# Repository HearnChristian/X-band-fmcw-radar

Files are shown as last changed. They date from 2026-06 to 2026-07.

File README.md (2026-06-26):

# (actually K)-Band FMCW Radar

A frequency-modulated continuous-wave (FMCW) radar front-end designed in KiCad —
a single-board transceiver intended for **ground-based ranging and weather /
precipitation sensing**. This repository holds the schematic capture, the
project's custom KiCad libraries, and the generated netlist. Work in progress.

## Architecture

FMCW radar works by transmitting a continuous tone whose frequency is swept
(chirped) linearly in time, then mixing the received echo against the
transmitted signal. The frequency of the resulting beat tone is proportional to
target range, so the whole signal chain is built around generating a clean,
linear chirp and digitizing the low-frequency beat note.

```
  Reference        Chirp synth        RF transceiver        Driver amp
  ┌────────┐      ┌──────────┐       ┌──────────────┐      ┌──────────┐
  │  TCXO  │─────▶│ ADF4159  │──────▶│ BGT24LTR11N16│─────▶│AMM-8211PSM│──▶ TX
  │ ref clk│      │ PLL/ramp │       │ 24 GHz Tx/Rx │      │ driver PA │
  └────────┘      └──────────┘       └──────┬───────┘      └──────────┘
                                            │ IF (beat)
                                            ▼
                       ┌──────────┐   ┌──────────┐   ┌──────────┐
                  Rx ──│ OPA1656  │──▶│ ADS8353  │──▶│ FT2232H  │──▶ USB host
                       │ IF amp   │   │ 16b ADC  │   │ USB 2.0  │
                       └──────────┘   └──────────┘   └──────────┘
```

## Key components

| Block | Part | Function |
|---|---|---|
| Chirp synthesizer | **ADF4159** | Fractional-N PLL with onboard ramp generator — produces the linear FMCW sweep |
| RF transceiver | **BGT24LTR11N16** | 24 GHz SiGe transmit/receive front-end with integrated VCO and downconversion |
| Driver amplifier | **AMM-8211PSM** | 22–57 GHz GaAs MMIC driver amp boosting the transmit chain |
| IF / baseband | **OPA1656** | Low-noise, low-distortion op-amp conditioning the beat-note signal |
| Data converter | **ADS8353** | Dual 16-bit SAR ADC sampling the IF |
| Host interface | **FT2232HL** | USB 2.0 bridge for control + data streaming |
| Reference clock | **ECS-TXO-2520MV** | TCXO frequency reference |
| Power | **TPS7A4700 / TPS7A2018 / TPS7A2033** | Ultra-low-noise LDOs for clean RF/analog rails |
| Config | **93LC56B** | EEPROM for FT2232 descriptor |

## Custom library work

The **AMM-8211PSM** driver amplifier had no vendor-supplied EDA data — only a
datasheet — so its schematic symbol and PCB footprint were built from scratch
from the Marki Microwave mechanical drawings:

```
AMM-8211PSM.kicad_sym                                          custom symbol
AMM-8211PSM.pretty/QFN-16-1EP_3x3mm_P0.5mm_EP1.1x1.1mm_Marki.kicad_mod   custom footprint
```

The footprint is a 3 × 3 mm 16-lead QFN, 0.5 mm pitch, with a 1.10 × 1.10 mm
exposed ground paddle and a 3 × 3 array of thermal vias, matching the Marki
outline drawing and pin assignment.

## Repository layout

```
Radar1.kicad_pro      KiCad project
Radar1.kicad_sch      Schematic (in progress)
Radar1.kicad_pcb      PCB layout (not yet started)
Radar1.net            Exported netlist
AMM-8211PSM.kicad_sym Custom symbol (see above)
AMM-8211PSM.pretty/   Custom footprint library
sym-lib-table         Project symbol-library table
fp-lib-table          Project footprint-library table
```

## Tools

Designed in [KiCad](https://www.kicad.org/) 9. Open `Radar1.kicad_pro` to view
the schematic.

---

*Author: Christian Hearn*

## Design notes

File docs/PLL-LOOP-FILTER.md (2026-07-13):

# PLL Loop Filter Design (Rev-E)

Chirp synthesizer loop: ADF4159 (PFD + charge pump) locks the BGT24LTR11
VCO through its ÷16 divider output. This note replaces the schematic-capture
placeholder values with a computed design (`tools/pll_loop_filter.py`).

## Loop parameters

| Parameter | Value | Source |
|---|---|---|
| f_REF = f_PFD | 50 MHz | ECS-TXO-2520MV-500 (Y1), R-counter = 1 |
| f_VCO | 24.05–24.25 GHz | BGT24LTR11 DS Table 5 (R_TUNE = 16 kΩ) |
| N (VCO→PFD) | 483 | includes BGT24 ÷16 (ADF4159 INT ≈ 30.2, frac) |
| Kvco | 720 MHz/V typ, 2000 MHz/V max | BGT24LTR11 DS Table 5 |
| V_TUNE range | 0.7–2.5 V | BGT24LTR11 DS; ADF4159 CP compliance 0.5–2.8 V ✓ |
| Icp | 2.5 mA design point | RSET = 5.1 kΩ → 0.31–5 mA in 16 steps |

## Topology fix

The captured filter was an all-shunt RC ladder (C17 ∥ → R3 → C18 ∥ → R4 →
C19 ∥ → V_TUNE). A current-driven RC ladder has **no finite zero at the
output node**, so a type-2 loop built on it is unconditionally unstable —
confirmed by exact network analysis. **Rev-E moves R4's input from the
R3/C18 junction to the charge-pump node**, restoring the standard 3rd-order
passive filter: the R3+C18 series branch at CPOUT provides the stabilizing
zero, R4/C19 form the spur-filter pole.

```
CPOUT ──┬────┬───── R4 (560R) ───┬──── V_TUNE
        │    │                   │
      C17   R3 (270R)          C19 (270pF)
     910pF   │                   │
        │  C18 (15nF)           GND
       GND   │
            GND
```

## Values and verified performance (exact ladder analysis)

C17 = 910 pF, R3 = 270 Ω, C18 = 15 nF, R4 = 560 Ω, C19 = 270 pF (E12/E24).

| Corner | f_c | Phase margin |
|---|---|---|
| Kvco typ, Icp 2.5 mA (design) | 146 kHz | 52° |
| Kvco max, Icp 2.5 mA | 331 kHz | 36° |
| Kvco typ, Icp 1.25 mA | 81 kHz | 51° |
| Kvco max, Icp 1.25 mA | 193 kHz | 49° |
| Kvco typ, Icp 5 mA | 259 kHz | 43° |

150 kHz sits near the noise-optimal crossover (ADF4159 in-band floor
≈ −90 dBc/Hz at N = 483 meets the VCO's −80 dBc/Hz @100 kHz, −20 dB/dec
a little above 300 kHz) and comfortably tracks the FMCW ramp
(250 MHz / 1 ms ≈ 0.35 V/ms on V_TUNE).

## Firmware notes

- Program Icp = 2.5 mA (setting 8/16). If lab tuning shows Kvco at the
  high end, drop to 1.25 mA rather than raising the bandwidth.
- R-counter = 1, reference doubler/divider off (f_PFD = 50 MHz).
- Keep **VCC_PTAT = 0 V**: the BGT24 divider is ÷16 only when V_PTAT is
  disabled; at 3.3 V it becomes ÷8192 and the loop constants are wrong.
- MUXOUT is open-drain 1.8 V logic (R22 pull-up to +1V8, Rev-D).

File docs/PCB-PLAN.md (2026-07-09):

# PCB Plan — Stackup Trade & Floorplan (pre-layout)

Base: schematic `21be641` (electrically identical to Rev-C `4aef776`, netlist-verified).
Date: 2026-07-09.

## Substrate decision

Only the three 24 GHz runs (TX chain to J3, RX feed from J4) and the 1.5 GHz
divided LO care about the substrate; everything else is DC/SPI/IF.

| Option | Dk | tan δ | ~Loss @24 GHz | Z₀ tol | Verdict |
|---|---|---|---|---|---|
| All FR4 | 4.2–4.6 (uncontrolled) | ~0.020 | 0.5–0.8 dB/cm | ±8–10 % | Reject — loss + Dk uncertainty eat the PA gain budget |
| **Hybrid RO4350B (10 mil) over FR4** | 3.48 ± 0.05 | 0.0037 | 0.10–0.15 dB/cm | ±2–3 % | **Pick** — all RF is on L1/L2; FR4 below carries power/digital |
| Full RO4350B | 3.48 ± 0.05 | 0.0037 | 0.10–0.15 dB/cm | ±2–3 % | Overkill — inner layers are DC/digital |

**Stackup (≈1.5 mm, ENIG):** L1 RF/signal — RO4350B 0.254 mm — L2 solid GND —
FR4 core ≈0.9 mm — L3 power — prepreg — L4 signal/GND.
50 Ω GCPW starting point: w ≈ 0.50 mm, gap ≈ 0.25 mm (field-solve against fab stackup).

## Floorplan (board ≈ 60 × 42 mm)

- **West edge:** J3 (TX) / J4 (RX) end-launch, ≥26.5 GHz rated (2.92 mm preferred).
  U12 PA driver between U1 and J3; U1 BGT24 center-west. 24 GHz GCPW with via
  fences (pitch ≤ 0.8 mm) both sides; stitching ring around RF zone.
- **PLL:** U2 ADF4159 east of U1; loop filter tight, guarded, nothing switching
  within 5 mm; Y1 50 MHz TCXO short/direct into REFIN.
- **Center:** IF chain U1 → U3 (OPA1656 ×3) → U8 ADS8353; U15 REF5025 adjacent.
- **East edge:** U7 FT2232H, U11 12 MHz, U10 EEPROM, J1 USB-C.
- **South strip:** J2 barrel (SE) → U6 5 V LDO (+ thermal pour) → LDO row.
  U9 ADP5600 (−VGG charge pump, the only switcher) far corner from RX, LC
  post-filter to PA gate. +3V3_RF / +3V3_DIG copper split mirrors the Rev-C rail split.
- Thermal: EP via arrays under U1, U12, U6, U13.

## Blockers before placement

1. **CRITICAL — ADF4159 SPI overvoltage.** FT2232H drives CLK/DATA/LE/CE/TXDATA
   at 3.3 V; ADF4159 digital abs-max = DVDD + 0.3 V = 2.1 V (datasheet Table 4).
   MUXOUT readback (1.8 V logic → 3.3 V-bank input) is marginal in reverse.
   Fix (no new parts): power FT2232H ADBUS-bank VCCIO from +1V8 (VCCIO spec
   1.62–3.63 V), and move ADS8353 DVDD from +3V3_RF to +1V8 (also removes ADC
   digital noise from the RF rail).
2. Footprint pass: ~12 symbols unassigned; 5 libs missing from `fp-lib-table`.
3. Sync embedded symbols with libs (USB4215-03-A, AMM-8211PSM mismatch).
4. Spec barrel input 6 V nominal (≤6.5 V) or add buck before U6 — LDO drops
   (VIN−5 V) × ~0.45 A.
5. Optional: route U1 V_PTAT to a spare ADC channel for temperature telemetry.

## Verified correct in this review

PA sequencing (ADP5600 PGOOD gates +3V0_PA enable), PA bias (Vd = 3 V/175 mA =
datasheet nominal), TPS7A4700 straps (5.0 V / 3.0 V exact), FT2232 VCORE loop,
ADF4159 rail split (AVDD 3.3 / DVDD 1.8). ERC "errors" are symbol pin-type
pedantry; netlist has no floating nets.

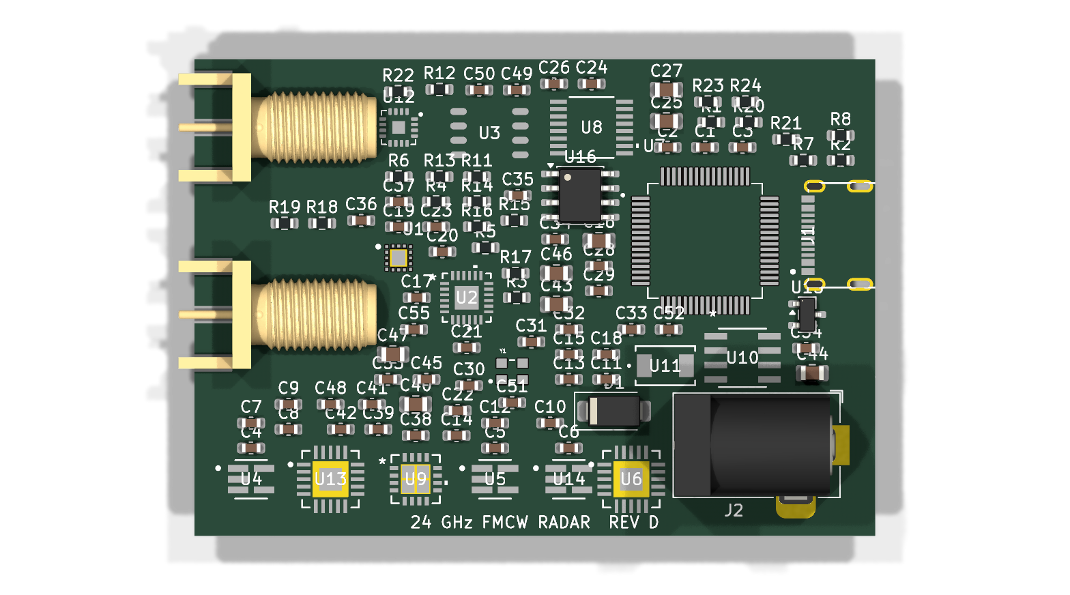
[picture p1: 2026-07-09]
docs/board-placement-top.png

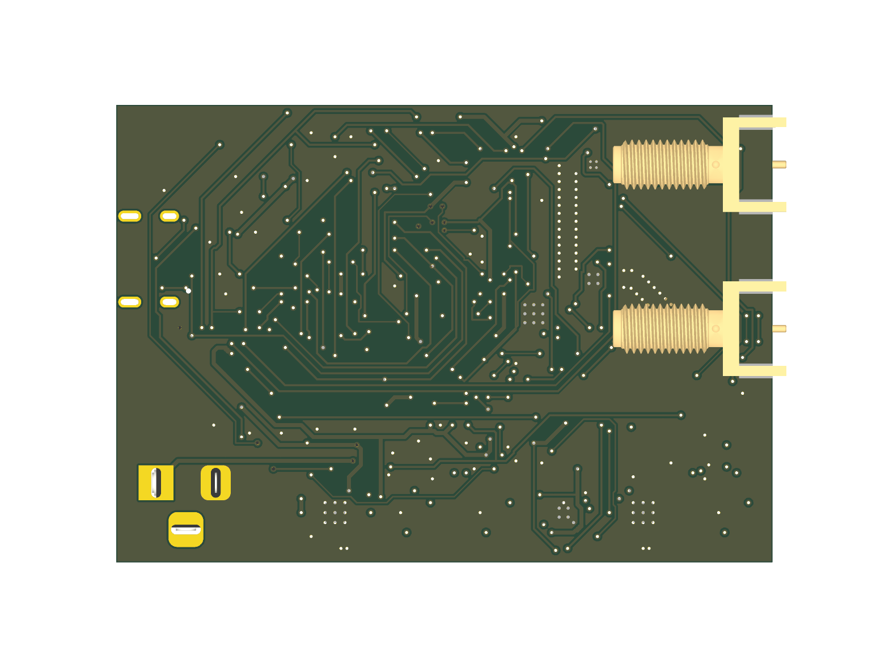
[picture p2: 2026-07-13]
docs/board-bottom.png

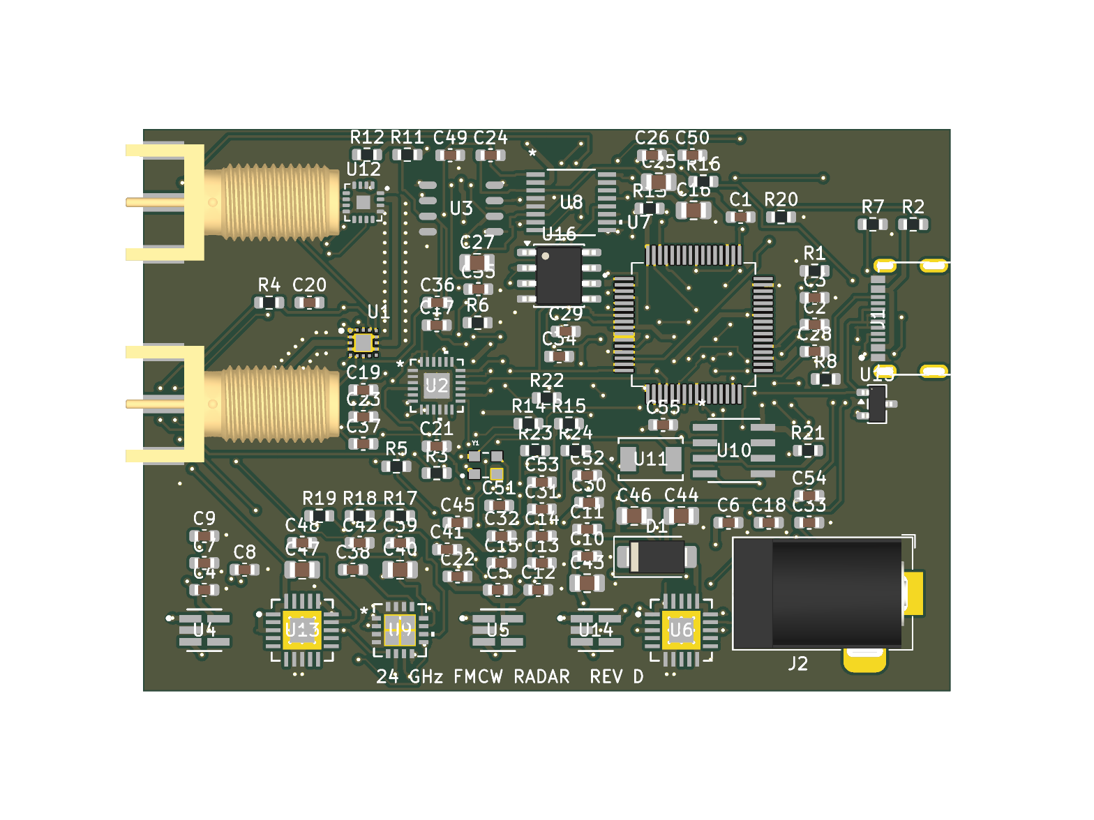
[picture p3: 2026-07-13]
docs/board-top.png

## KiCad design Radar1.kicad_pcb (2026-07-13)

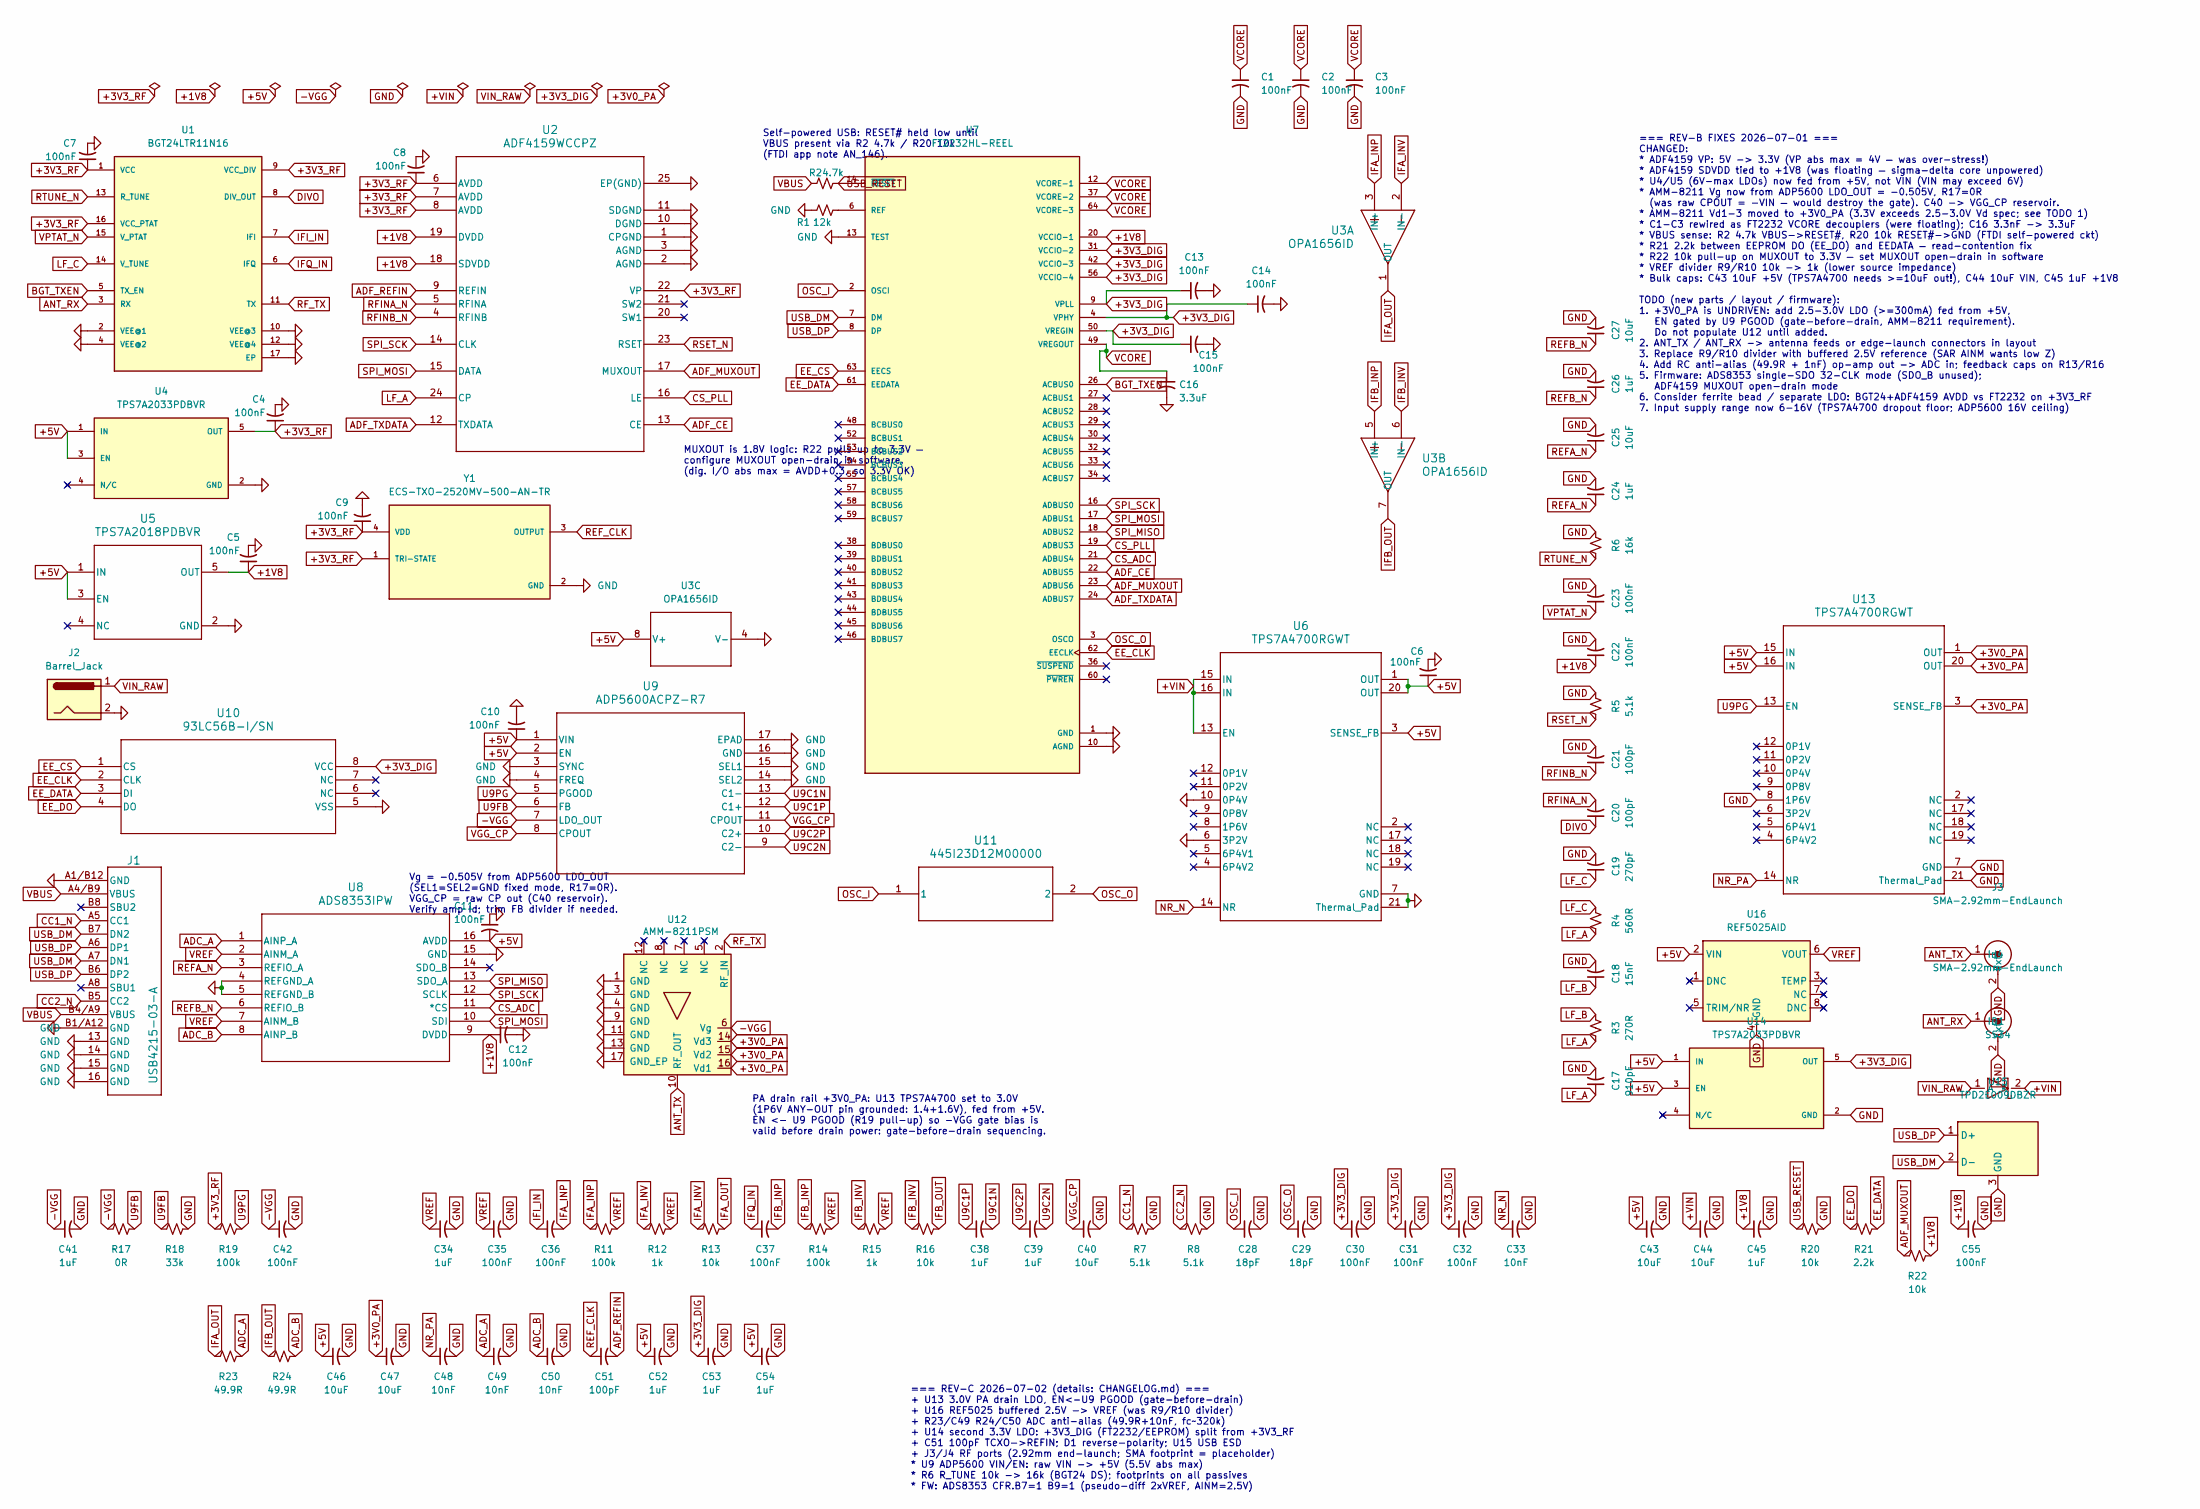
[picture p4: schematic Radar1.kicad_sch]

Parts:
C1, C2, C3, C4, C5, C6, C7, C8, C9, C10, C11, C12, C13, C14, C15, C22, C23, C30, C31, C32, C35, C36, C37, C42, C55: 100nF; C_0603_1608Metric
C16: 3.3uF; C_0805_2012Metric
C17: 910pF; C_0603_1608Metric
C18: 15nF; C_0603_1608Metric
C19: 270pF; C_0603_1608Metric
C20, C21, C51: 100pF; C_0603_1608Metric
C24, C26, C34, C38, C39, C41, C45, C52, C53, C54: 1uF; C_0603_1608Metric
C25, C27, C40, C43, C44, C46, C47: 10uF; C_0805_2012Metric
C28, C29: 18pF; C_0603_1608Metric
C33, C48, C49, C50: 10nF; C_0603_1608Metric
D1: SS34; D_SMA
J1: USB4215-03-A; CONN_8p94X6p5X3p16_12L_GCC
J2: Barrel_Jack; BarrelJack_Horizontal
J3, J4: SMA-2.92mm-EndLaunch; SMA_Amphenol_132289_EdgeMount
R1: 12k; R_0603_1608Metric
R2: 4.7k; R_0603_1608Metric
R3: 270R; R_0603_1608Metric
R4: 560R; R_0603_1608Metric
R5, R7, R8: 5.1k; R_0603_1608Metric
R6: 16k; R_0603_1608Metric
R11, R14, R19: 100k; R_0603_1608Metric
R12, R15: 1k; R_0603_1608Metric
R13, R16, R20, R22: 10k; R_0603_1608Metric
R17: 0R; R_0603_1608Metric
R18: 33k; R_0603_1608Metric
R21: 2.2k; R_0603_1608Metric
R23, R24: 49.9R; R_0603_1608Metric
U1: BGT24LTR11N16; PQFN50P240X240X77-17N-V
U2: ADF4159WCCPZ; CP_24_10
U3: OPA1656ID; D0008A_N
U4, U14: TPS7A2033PDBVR; DBV0005A-IPC_A; PARTREV H
U5: TPS7A2018PDBVR; DBV0005A-IPC_A
U6, U13: TPS7A4700RGWT; RGW0020A-IPC_A
U7: FT2232HL-REEL; QFP50P1200X1200X160-64N
U8: ADS8353IPW; PW16_TEX
U9: ADP5600ACPZ-R7; CP-16-17_ADI
U10: 93LC56B-I/SN; SOIC8-N_MC_MCH
U11: 445I23D12M00000; 445I23D12M00000_CTS
U12: AMM-8211PSM; QFN-16-1EP_3x3mm_P0.5mm_EP1.1x1.1mm_Marki; MPN AMM-8211PSM-22
U15: TPD2E009DBZR; SOT-23
U16: REF5025AID; SOIC-8_3.9x4.9mm_P1.27mm
Y1: ECS-TXO-2520MV-500-AN-TR; OSC_ECS-TXO-2520MV-500-AN-TR; PARTREV 2017

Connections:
+1V8: C5.1, C12.1, C22.1, C45.1, C55.1, R22.2, U2.18 (SDVDD), U2.19 (DVDD), U5.5 (OUT), U7.20 (VCCIO-1), U8.9 (DVDD)
+3V0_PA: C47.1, U12.14 (Vd3), U12.15 (Vd2), U12.16 (Vd1), U13.1 (OUT), U13.3 (SENSE_FB), U13.20 (OUT)
+3V3_DIG: C13.1, C14.1, C15.1, C30.1, C31.1, C32.1, C53.1, U7.4 (VPHY), U7.9 (VPLL), U7.31 (VCCIO-2), U7.42 (VCCIO-3), U7.50 (VREGIN), U7.56 (VCCIO-4), U10.8 (VCC), U14.5 (OUT)
+3V3_RF: C4.1, C7.1, C8.1, C9.1, R19.1, U1.1 (VCC), U1.9 (VCC_DIV), U1.16 (VCC_PTAT), U2.6 (AVDD), U2.7 (AVDD), U2.8 (AVDD), U2.22 (VP), U4.5 (OUT), Y1.1 (TRI-STATE), Y1.4 (VDD)
+5V: C6.1, C10.1, C11.2, C43.1, C46.1, C52.1, C54.1, U3.8 (V+), U4.1 (IN), U4.3 (EN), U5.1 (IN), U5.3 (EN), U6.1 (OUT), U6.3 (SENSE_FB), U6.20 (OUT), U8.16 (AVDD), U9.1 (VIN), U9.2 (EN), U13.15 (IN), U13.16 (IN), U14.1 (IN), U14.3 (EN), U16.2 (VIN)
+VIN: C44.1, D1.2 (K), U6.13 (EN), U6.15 (IN), U6.16 (IN)
-VGG: C41.1, C42.1, R17.1, U9.7 (LDO_OUT), U12.6 (Vg)
ADC_A: C49.1, R23.2, U8.1 (AINP_A)
ADC_B: C50.1, R24.2, U8.8 (AINP_B)
ADF_CE: U2.13 (CE), U7.22 (ADBUS5)
ADF_MUXOUT: R22.1, U2.17 (MUXOUT), U7.23 (ADBUS6)
ADF_REFIN: C51.2, U2.9 (REFIN)
ADF_TXDATA: U2.12 (TXDATA), U7.24 (ADBUS7)
ANT_RX: J4.1 (In), U1.3 (RX)
ANT_TX: J3.1 (In), U12.10 (RF_OUT)
BGT_TXEN: U1.5 (TX_EN), U7.26 (ACBUS0)
CC1_N: J1.A5 (CC1), R7.1
CC2_N: J1.B5 (CC2), R8.1
CS_ADC: U7.21 (ADBUS4), U8.11 (*CS)
CS_PLL: U2.16 (LE), U7.19 (ADBUS3)
DIVO: C20.1, U1.8 (DIV_OUT)
EE_CLK: U7.62 (EECLK), U10.2 (CLK)
EE_CS: U7.63 (EECS), U10.1 (CS)
EE_DATA: R21.2, U7.61 (EEDATA), U10.3 (DI)
EE_DO: R21.1, U10.4 (DO)
GND: C1.2, C2.2, C3.2, C4.2, C5.2, C6.2, C7.2, C8.2, C9.2, C10.2, C11.1, C12.2, C13.2, C14.2, C15.2, C16.2, C17.2, C18.2, C19.2, C21.2, C22.2, C23.2, C24.2, C25.2, C26.2, C27.2, C28.2, C29.2, C30.2, C31.2, C32.2, C33.2, C34.2, C35.2, C40.2, C41.2, C42.2, C43.2, C44.2, C45.2, C46.2, C47.2, C48.2, C49.2, C50.2, C52.2, C53.2, C54.2, C55.2, J1.13 (GND), J1.14 (GND), J1.15 (GND), J1.16 (GND), J1.A1/B12 (GND), J1.B1/A12 (GND), J2.2, J3.2 (Ext), J4.2 (Ext), R1.1, R5.2, R6.2, R7.2, R8.2, R18.2, R20.2, U1.2 (VEE@1), U1.4 (VEE@2), U1.10 (VEE@3), U1.12 (VEE@4), U1.17 (EP), U2.1 (CPGND), U2.2 (AGND), U2.3 (AGND), U2.10 (DGND), U2.11 (SDGND), U2.25 (EP(GND)), U3.4 (V-), U4.2 (GND), U5.2 (GND), U6.6 (3P2V), U6.7 (GND), U6.10 (0P4V), U6.21 (Thermal_Pad), U7.1 (GND), U7.5 (GND), U7.10 (AGND), U7.11 (GND), U7.13 (TEST), U7.15 (GND), U7.25 (GND), U7.35 (GND), U7.47 (GND), U7.51 (GND), U8.4 (REFGND_A), U8.5 (REFGND_B), U8.15 (GND), U9.3 (SYNC), U9.4 (FREQ), U9.14 (SEL2), U9.15 (SEL1), U9.16 (GND), U9.17 (EPAD), U10.5 (VSS), U12.1 (GND), U12.3 (GND), U12.4 (GND), U12.9 (GND), U12.11 (GND), U12.13 (GND), U12.17 (GND_EP), U13.7 (GND), U13.8 (1P6V), U13.21 (Thermal_Pad), U14.2 (GND), U15.3 (GND), U16.4 (GND), Y1.2 (GND)
IFA_INP: C36.2, R11.1, U3.3 (IN+)
IFA_INV: R12.1, R13.1, U3.2 (IN-)
IFA_OUT: R13.2, R23.1, U3.1 (OUT)
IFB_INP: C37.2, R14.1, U3.5 (IN+)
IFB_INV: R15.1, R16.1, U3.6 (IN-)
IFB_OUT: R16.2, R24.1, U3.7 (OUT)
IFI_IN: C36.1, U1.7 (IFI)
IFQ_IN: C37.1, U1.6 (IFQ)
LF_A: C17.1, R3.1, R4.1, U2.24 (CP)
LF_B: C18.1, R3.2
LF_C: C19.1, R4.2, U1.14 (V_TUNE)
NR_N: C33.1, U6.14 (NR)
NR_PA: C48.1, U13.14 (NR)
unnamed: R1.2, U7.6 (REF)
OSC_I: C28.1, U7.2 (OSCI), U11.1
OSC_O: C29.1, U7.3 (OSCO), U11.2
REFA_N: C24.1, C25.1, U8.3 (REFIO_A)
REFB_N: C26.1, C27.1, U8.6 (REFIO_B)
REF_CLK: C51.1, Y1.3 (OUTPUT)
RFINA_N: C20.2, U2.5 (RFINA)
RFINB_N: C21.1, U2.4 (RFINB)
RF_TX: U1.11 (TX), U12.2 (RF_IN)
RSET_N: R5.1, U2.23 (RSET)
RTUNE_N: R6.1, U1.13 (R_TUNE)
SPI_MISO: U7.18 (ADBUS2), U8.13 (SDO_A)
SPI_MOSI: U2.15 (DATA), U7.17 (ADBUS1), U8.10 (SDI)
SPI_SCK: U2.14 (CLK), U7.16 (ADBUS0), U8.12 (SCLK)
U9C1N: C38.2, U9.13 (C1-)
U9C1P: C38.1, U9.12 (C1+)
U9C2N: C39.2, U9.9 (C2-)
U9C2P: C39.1, U9.10 (C2+)
U9FB: R17.2, R18.1, U9.6 (FB)
U9PG: R19.2, U9.5 (PGOOD), U13.13 (EN)
USB_DM: J1.A7 (DN1), J1.B7 (DN2), U7.7 (DM), U15.2 (D-)
USB_DP: J1.A6 (DP1), J1.B6 (DP2), U7.8 (DP), U15.1 (D+)
USB_RESET: R2.2, R20.1, U7.14 (~RESET)
VBUS: J1.A4/B9 (VBUS), J1.B4/A9 (VBUS), R2.1
VCORE: C1.1, C2.1, C3.1, C16.1, U7.12 (VCORE-1), U7.37 (VCORE-2), U7.49 (VREGOUT), U7.64 (VCORE-3)
VGG_CP: C40.1, U9.8 (CPOUT), U9.11 (CPOUT)
VIN_RAW: D1.1 (A), J2.1
VPTAT_N: C23.1, U1.15 (V_PTAT)
VREF: C34.1, C35.1, R11.2, R12.2, R14.2, R15.2, U8.2 (AINM_A), U8.7 (AINM_B), U16.6 (VOUT)

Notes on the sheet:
Vg = -0.505V from ADP5600 LDO_OUT (SEL1=SEL2=GND fixed mode, R17=0R). VGG_CP = raw CP out (C40 reservoir). Verify amp Id; trim FB divider if needed.
=== REV-C 2026-07-02 (details: CHANGELOG.md) === + U13 3.0V PA drain LDO, EN<-U9 PGOOD (gate-before-drain) + U16 REF5025 buffered 2.5V -> VREF (was R9/R10 divider) + R23/C49 R24/C50 ADC anti-alias (49.9R+10nF, fc~320k) + U14 second 3.3V LDO: +3V3_DIG (FT2232/EEPROM) split from +3V3_RF + C51 100pF T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
Self-powered USB: RESET# held low until VBUS present via R2 4.7k / R20 10k (FTDI app note AN_146).
=== REV-B FIXES 2026-07-01 === CHANGED: * ADF4159 VP: 5V -> 3.3V (VP abs max = 4V — was over-stress!) * ADF4159 SDVDD tied to +1V8 (was floating — sigma-delta core unpowered) * U4/U5 (6V-max LDOs) now fed from +5V, not VIN (VIN may exceed 6V) * AMM-8211 Vg now from ADP5600 LDO_OUT = -0.505V, R17=0R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
MUXOUT is 1.8V logic: R22 pulls up to 3.3V — configure MUXOUT open-drain in software. (dig. I/O abs max = AVDD+0.3, so 3.3V OK)
PA drain rail +3V0_PA: U13 TPS7A4700 set to 3.0V (1P6V ANY-OUT pin grounded: 1.4+1.6V), fed from +5V. EN <- U9 PGOOD (R19 pull-up) so -VGG gate bias is valid before drain power: gate-before-drain sequencing.

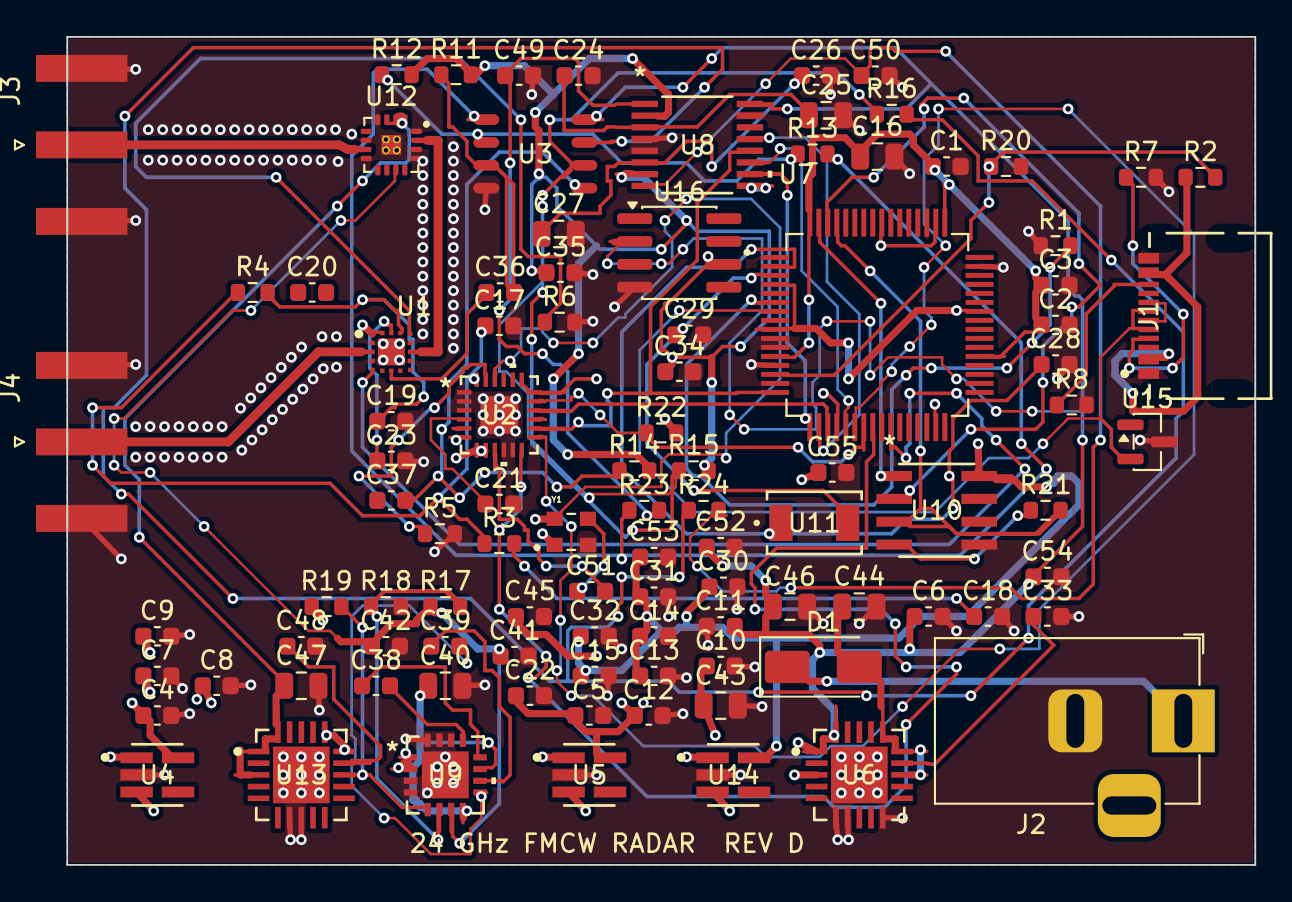
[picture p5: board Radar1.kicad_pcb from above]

Board: 4 copper layers, 66.0 x 46.0 mm, 99 parts (0 on the bottom side), 68 nets.

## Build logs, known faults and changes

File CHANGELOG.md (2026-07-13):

# Changelog

## Board bring-up — 2026-07-09

`Radar1.kicad_pcb` generated (text-built from netlist + `docs/PCB-PLAN.md`
floorplan; generator in `tools/board_gen.py`):

- **4-layer hybrid stackup** defined: F.Cu / RO4350B 0.254 mm (εr 3.48,
  tanδ 0.0037) / In1.Cu GND / FR4 0.9 mm / In2.Cu PWR / FR4 0.2 mm / B.Cu,
  ENIG finish, 1.545 mm total. All 24 GHz returns reference In1.Cu directly
  under the Rogers layer.
- **Board 60 × 42 mm**, outline + title silk. All 99 components placed:
  ICs/connectors at floorplan coordinates (RF west, PLL center, digital east,
  power south), passives auto-packed beside their owner ICs (netlist-driven
  ownership, bbox collision packing).
- **Net classes**: RF (0.5 mm track) for ANT_TX/ANT_RX/RF_TX, PWR (0.4 mm),
  Default clearance 0.15 mm (vendor fine-pitch QFNs have 0.175 mm pad gaps).
- **DRC: zero placement violations.** Remaining: 293 unconnected (unrouted —
  next phase) and 10 copper-edge items on J3/J4, expected by design: the
  Amphenol edge-launch pads intentionally overlap the board edge (standard
  waiver; the placeholder SMAs get real 2.92 mm launches before fab).
- Render: `docs/board-placement-top.png`.

Next: GCPW RF routing (w 0.50 / gap 0.25 mm + via fences), power pours, SPI.

## Footprint pass — 2026-07-09

Every IC/connector footprint is now assigned and resolvable; layout is unblocked.

- New project library **`RadarFP.pretty`** (registered in `fp-lib-table`) with 12
  vendor/UltraLibrarian footprints recovered from the part archives in
  `~/Downloads` (they had been downloaded with the symbols but never installed):
  BGT24 PQFN-16, ADF4159 CP-24-10, ADP5600 CP-16-17, ADS8353 PW-16,
  OPA1656 D-8, TPS7A20 DBV-5, TPS7A4700 RGW-20 (IPC_A variant — the MFG variant
  splits the EP into 10 separately numbered tiles and breaks pin mapping),
  FT2232H LQFP-64, 93LC56B SOIC-8, CTS 445 crystal, ECS-TXO-2520MV, GCT USB4215.
- All pad numbering validated against schematic symbol pins (incl. EP numbers:
  ADF4159 EP=25, ADP5600 EP=17, BGT24 EP=17); dimensions sanity-checked against
  package tables; render preview in `docs/footprints-preview.png`.
- U4/U14 (TPS7A2033, SOT-23-5/DBV) repointed to the DBV footprint — the
  previously referenced `TPS7A2033PDBVR:SOT95P280X145-5N` never existed on disk
  and the downloaded TPS7A2033 archive was the wrong package variant (DQN).
- Stray `Designator*` silkscreen text removed from the DBV and RGW footprints.
- Netlist connectivity verified unchanged; ERC footprint_link_issues 17 → 0.

## Rev D — 2026-07-09

SPI level-domain fix (found in pre-layout review; ADF4159 DS Rev E, Table 4).

### Problem
FT2232H drove ADF4159 CLK/DATA/LE/CE/TXDATA at 3.3 V logic, but the ADF4159
digital absolute maximum is DVDD + 0.3 V = 2.1 V — a 5-pin abs-max violation.
MUXOUT readback (1.8 V logic into a 3.3 V-referenced input) was marginal in
the reverse direction.

### Changed (zero new part types)
- **U7 pin 20 (VCCIO, ADBUS bank)** `+3V3_DIG` → `+1V8`. The ADBUS SPI bank now
  runs at 1.8 V natively (FT2232H VCCIO spec: 1.62–3.63 V, per FTDI AN_146).
  Other VCCIO banks (pins 31/42/56) stay at 3.3 V — EEPROM interface unchanged.
- **U8 pin 9 (ADS8353 DVDD)** `+3V3_RF` → `+1V8` (DVDD spec 1.65–3.6 V). The ADC
  shares the ADBUS SPI bus, so its I/O follows the 1.8 V domain — and this
  removes ADC digital switching noise from the RF/analog 3.3 V rail (C12
  decoupler rides along).
- **R22 (MUXOUT pull-up)** `+3V3_DIG` → `+1V8`. Open-drain MUXOUT plan from
  Rev B still applies, now pulling to the correct domain.
- **C55 100 nF** added on `+1V8` — local decoupling for the re-domained VCCIO
  bank (+1V8 previously had only C5/C22/C45 near U5/U2).

Verified by netlist regression (exact 5-pin expected transform, nothing else
moved) and ERC (identical message set before/after). +1V8 load additions are
~10–20 mA against TPS7A2018 headroom.

## Rev C — 2026-07-02

Functional-gap pass: every block needed for a working board (except antenna
feeds) is now present and driven.

### Added
- **U13 (TPS7A4700)** — 3.0 V PA drain LDO for the AMM-8211 (`+3V0_PA` was an
  undriven net). Output set by grounding the 1P6V ANY-OUT pin (1.4 + 1.6 V).
  Fed from +5 V; **EN driven by U9 (ADP5600) PGOOD** so the −0.5 V gate bias is
  established before drain power: gate-before-drain sequencing for the GaAs
  HEMT. AMM-8211 draws 175 mA typ (datasheet EC table, Vd = 3 V); the LDO is
  good for 1 A. C46/C47 input/output caps, C48 noise-reduction cap.
- **U16 (REF5025)** — buffered precision 2.5 V driving `VREF`. Replaces the
  R9/R10 1 kΩ divider: ADS8353 AINM inputs must sit within VREF ± 0.1 V and are
  sampled, so they need a low-impedance source, not a 500 Ω divider. C54 supply
  bypass; existing C34/C35 serve as output caps (REF50xx prefers 1–1.5 Ω ESR —
  verify, or add ~1 Ω in series at layout).
- **R23/C49, R24/C50** — anti-alias / charge-reservoir RC (49.9 Ω + 10 nF C0G,
  fc ≈ 320 kHz) between the OPA1656 outputs and ADS8353 AINP_A/B
  (new nets `ADC_A`/`ADC_B`).
- **U14 (TPS7A2033)** — second 3.3 V LDO creating `+3V3_DIG` for the FT2232
  (VCCIO ×4, VPHY, VPLL, VREGIN), EEPROM, and the MUXOUT pull-up, with
  C13–C15/C30–C32 moved over. `+3V3_RF` now feeds only ADF4159, BGT24LTR11 and
  the TCXO. Previously one 300 mA LDO carried ~230–280 mA of combined load and
  put USB switching noise on the PLL/VCO rail.
- **C51 (100 pF)** — AC coupling between the TCXO output and ADF4159 REFIN
  (new net `ADF_REFIN`), per ADF4159 reference-input practice.
- **D1 (SS34)** — reverse-polarity Schottky after the barrel jack (new net
  `VIN_RAW`). Recommended supply ~6 V: at 12 V input, U6 would dissipate ~4 W.
- **U15 (TPD2E009)** — USB ESD protection array on USB_DP/USB_DM.
- **J3/J4** — board-side RF ports for `ANT_TX`/`ANT_RX`. At 24 GHz use 2.92 mm
  (K) end-launch connectors; the assigned stock SMA edge-mount footprint is a
  **placeholder** to be replaced during layout. No series DC blocks needed —
  the AMM-8211 RF ports are internally DC-blocked (Marki datasheet).

### Changed
- **U9 (ADP5600) VIN/EN moved from raw VIN to +5 V.** Absolute max input is
  5.5 V while the TPS7A4700 needs > 5.3 V input to regulate — no valid supply
  voltage satisfied both. Input bypass C10 moved with it.
- **R6 (BGT24LTR11 R_TUNE) 10 k → 16 k** — datasheet spec condition for the
  24.05–24.25 GHz VCO range.
- Footprints assigned to **all** passives (0603; 10 µF/3.3 µF in 0805) and J2.
- Sheet A4 → A3 (content overflowed the A4 border).
- New symbols live in the project library `RadarExtra.kicad_sym`.

### Firmware notes
- ADS8353: CFR.B7 = 1, CFR.B9 = 1 (pseudo-differential, 2×VREF range,
  AINM = 2.5 V, AINP swings 0–5 V); single-SDO 32-CLK mode.
- ADF4159: configure MUXOUT as open-drain (R22 pulls up to 3.3 V digital rail).

### Still open
- Antenna feed line design + real 2.92 mm end-launch footprints (layout).
- PLL loop filter values are placeholders — recompute from Kvco/Icp/N.
- IF gain ×11 is a placeholder pending link-budget analysis.
- REF5025 output-cap ESR check (see above).

## Rev B — 2026-07-01

Datasheet-verification pass over the fully wired schematic (ERC 50 → 11).

- ADF4159 VP 5 V → 3.3 V (4 V abs max — was over-stressed); SDVDD tied to +1V8
  (was floating).
- U4/U5 (6 V-max LDOs) re-fed from +5 V instead of raw VIN.
- AMM-8211 Vg moved from raw charge-pump output to the ADP5600 regulated
  −0.505 V LDO output (SEL1 = SEL2 = GND fixed mode, R17 → 0 R); Vd1–3 moved to
  new `+3V0_PA` net (LDO added in Rev C).
- FT2232: C1–C3 rewired as VCORE decouplers (100 nF), C16 3.3 nF → 3.3 µF,
  VBUS sense divider (R2/R20) into RESET# for self-powered configuration,
  R21 EEPROM DO isolation, R22 MUXOUT pull-up.
- Bulk caps C43–C45; VREF divider stiffened (superseded by REF5025 in Rev C);
  29 no-connect flags; GND moved onto J1 B1/A12 (was 3.81 mm off-pin).

## Rev A — 2026-06-26

Initial full wiring: 8 → 58 connected nets, 43 components added. Regulators,
TCXO reference, PLL loop filter + DIV_OUT feedback, TX → AMM-8211, IF stage,
SPI/USB/EEPROM, ADP5600 → −VGG gate bias.

## Rev-E (2026-07-13)

- PLL loop filter redesigned from datasheet parameters (docs/PLL-LOOP-FILTER.md):
  topology fix (R4 input moved from R3/C18 junction to CPOUT — the captured
  ladder had no stabilizing zero and could not lock), values 910pF/270R/15nF/
  560R/270pF for fc=146kHz, PM=52deg at Kvco typ, Icp 2.5mA.
- Board updated surgically: R4.1 re-netted, LF_A/LF_B rerouted, values synced.

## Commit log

2026-06-26 Wire signal chain: PLL, IF, RF, USB/SPI, bias networks (WIP checkpoint)
    Connected nets 8 -> 58; added 43 components. All connections verified by
    kicad-cli netlist export with regression checks; ERC clean of real shorts.
    - Regulators: TPS7A4700 programmed to 5.0V + NR cap
    - Reference: TCXO -> ADF4159 REFIN, enable tied high
    - PLL: 3rd-order loop filter (CP->V_TUNE), DIV_OUT->RFINA feedback, RSET,
    SDVDD decouple, BGT24 R_TUNE/V_PTAT/VCC_PTAT
    - TX: BGT24 TX -> AMM-8211 RF_IN, AMM drain bias + decoupling
    - IF/RX: placed missing OPA1656 power unit, fixed mis-wired inputs, added
    mid-rail VREF + non-inverting gain (x11) on I/Q, OUT -> ADS8353, ref caps
    - Digital: SPI bus (FT2232 <-> ADF4159 <-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
    [Radar1.kicad_sch]
2026-07-09 Add pre-layout PCB plan: hybrid RO4350B stackup, floorplan, blockers (incl. ADF4159 SPI level fix)
2026-07-09 Rev-D: move FT2232 ADBUS bank, ADS8353 DVDD, MUXOUT pull-up to 1.8V domain
    Fixes ADF4159 digital abs-max violation (3.3V into DVDD+0.3V=2.1V pins).
    Netlist-regression verified; ERC unchanged.
    [Radar1.kicad_sch]
2026-07-09 Board bring-up: 4-layer RO4350B hybrid stackup, 60x42mm outline, all 99 parts placed per floorplan
    Text-generated from netlist (tools/board_gen.py). DRC clean except unrouted
    ratsnest and documented edge-launch waivers on J3/J4.
    [Radar1.kicad_pcb]
2026-07-13 Update board renders
2026-07-13 Add route_move.py (part-move experiment): moving parts frees pads, not tracks
    C19/R22 relocation healed LF_C/+1V8 but re-split the moved nets; net
    negative (22->25), board reverted. Lesson: closing the last 6 nets needs
    rip+move+reroute as one operation, or interactive routing.
2026-07-13 Rev-E: PLL loop filter redesign — topology fix + computed values
    The captured loop filter was an all-shunt RC ladder: a current-driven
    ladder has no finite zero at V_TUNE, making the type-2 loop
    unconditionally unstable (verified by exact network analysis, see
    tools/pll_loop_filter.py). R4's input moves from the R3/C18 junction to
    CPOUT, restoring the standard 3rd-order passive topology.
    Values from BGT24LTR11 DS (Kvco 720M/2G Hz/V, VTUNE 0.7-2.5V, /16) and
    ADF4159 (RSET 5.1k, Icp 2.5mA, fPFD 50MHz, N=483):
    C17 910pF, R3 270R, C18 15nF, R4 560R, C19 270pF
    -> fc 146 kHz, PM 52 deg (typ); all corners in docs/PLL-LOOP-FILTER.md.
    Schematic: R4.1 global label LF_B->LF_A + 5 values (netlist re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
    [Radar1.kicad_pcb, Radar1.kicad_sch]
